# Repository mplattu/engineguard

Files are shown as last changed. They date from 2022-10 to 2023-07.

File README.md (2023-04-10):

# EngineGuard

Yacht engine room monitor based on ESP32 monitoring following sensors:
 * Temperature of engines 1 & 2 (DS18B20 temperature sensor)
 * Temperature of engine room above engines 1 & 2 (DS18B20 temperature sensor)
 * Oil pressure from engines 1 & 2 (+24V DC from VDO oil pressure sensor)
 * Engine room smoke sensor
 * Kitchen gas sensor

Intended operation:
 1. Any of the sensors report an emergency.
 1. An internal buzzers gives signal. This is mainly for debugging the device.
 1. An external 24V device gives signal. The device is connected via a reed relay.
 1. The OLED shows the reason for the alarm.
 1. The external signal can be cut for certain period of time by pressing a button.

## Project Status

 * We have a working code for all the sensors.
 * The PCB v4 was installed to the boat. It turned out that 24V to 5V conversion based on
   the voltage regulator 7805 created too much heat. Therefore, an external step down
   converter was introduced.
 * The PCB v5 has not neither been produced or field tested.

Main unit (green = power, red = activity): \
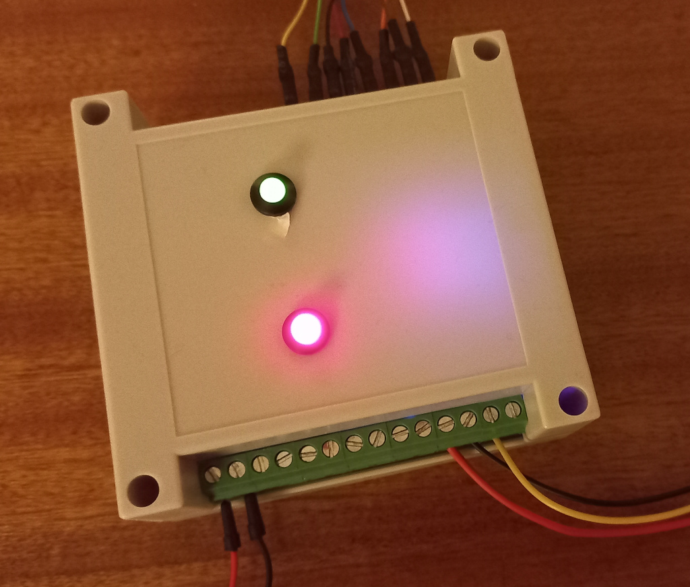
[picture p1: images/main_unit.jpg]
Main unit


Display unit: \
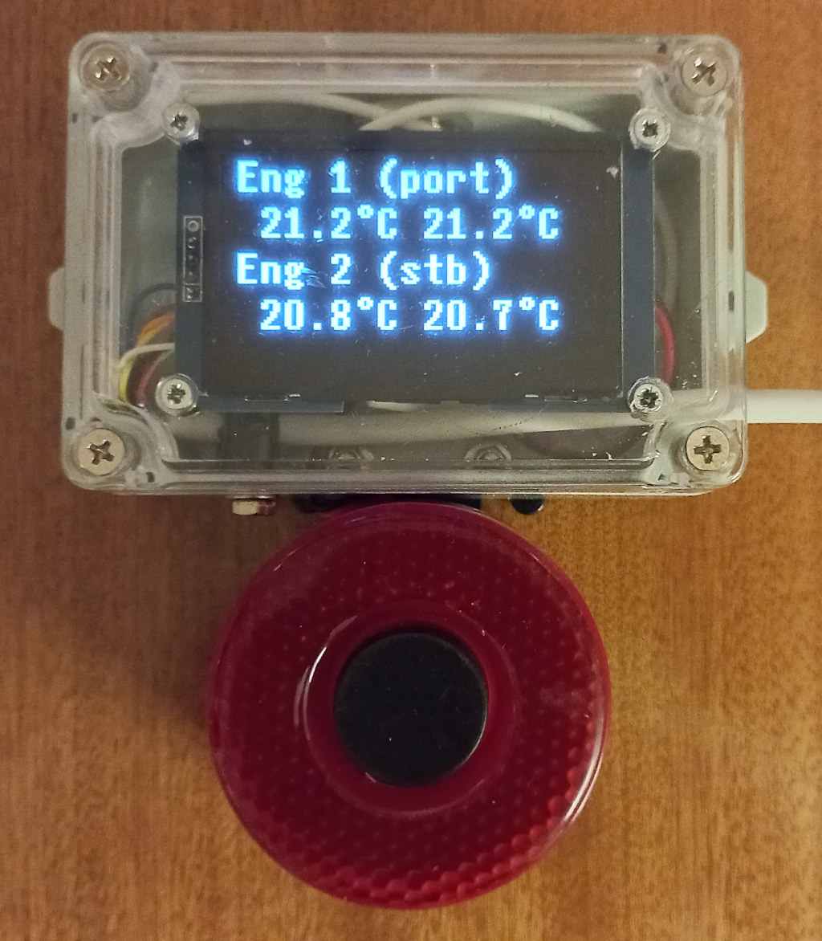
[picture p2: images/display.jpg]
Display


Acknowledgement button mounted to the top of the display unit: \
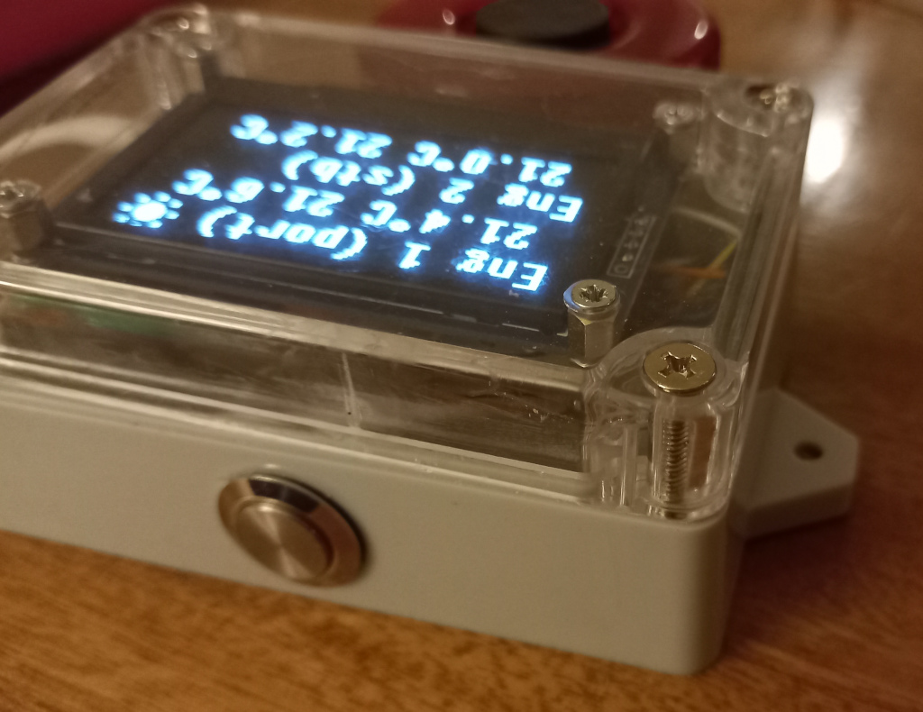
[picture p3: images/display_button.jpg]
Acknowledgement button


PCB: \
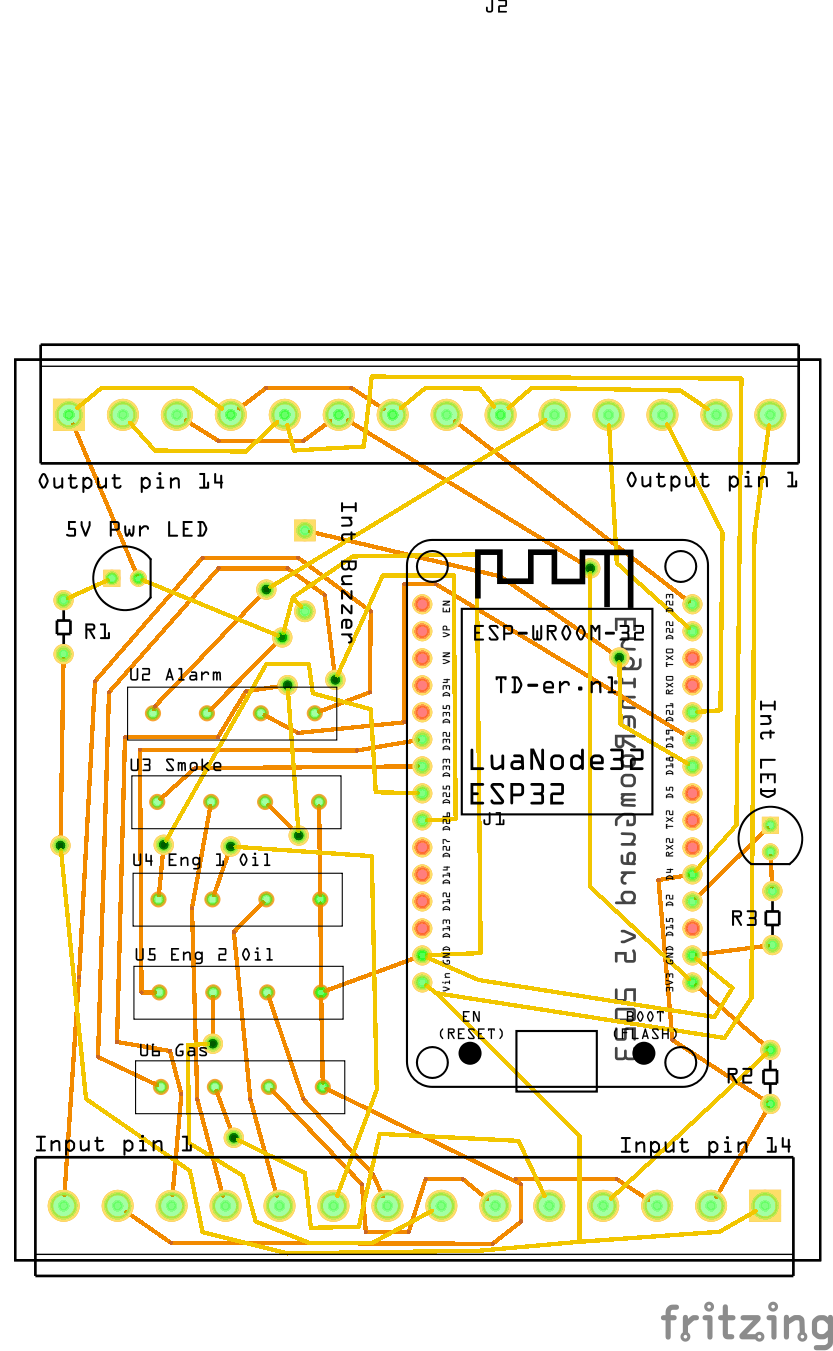
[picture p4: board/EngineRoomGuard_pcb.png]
PCB


## Technical Details

### Schematic and PCBs

See `board/` for Fritzing schematic & PCB and Gerber PCB files.

### Components

* U1 ESP-WROOM-32
* U2 5V reed relay with protective diode, Meder SIL05-1A72-71D ([Local electronics shop](https://www.partco.fi/fi/saehkoemekaniikka/releet/reed-releet/7411-rr-05-sild.html))
* U3-U6 24V reed relay with protective diode, Meder SIL24-1A72-71D ([Local electronics shop](https://www.partco.fi/fi/saehkoemekaniikka/releet/reed-releet/7413-rr-24-sild.html))
* OLED screen with SSD1309 driver, I2C version ([Aliexpress](https://www.aliexpress.com/item/1005003787866468.html))
* LED1, LED2 5mm LED in THT package
* R1 resistor 330 ohm
* R2 resistor 4,7 kOhm
* External DC 24V to DC 5V step down converter ([Joy IT SBC-Buck04-5V](https://joy-it.net/en/products/SBC-Buck04-5V))
* Box for central unit including J1 and J2 ([Aliexpress](https://www.aliexpress.com/item/1005003153480194.html))
* J3 internal piezo 3V ([Local electronics shop](https://www.partco.fi/fi/audiovideo/summerit/20187-summeri-3v.html))
* Box for screen and cancel button ([Aliexpress](https://www.aliexpress.com/item/4000081121421.html))
* Acknowledgement button ([Aliexpress](https://www.aliexpress.com/item/1005003105511055.html))
* Smoke Detector: Orbis Marine Multisensor Detector [ORB-OH-43003-MAR](https://www.apollo-fire.co.uk/products/orbis-marine/smokeheat-detectors/orb-oh-43003-mar---orbis-marine-multi-sensor-detector-opticalheat---flashing-led/) and Orbis Marine Relay Base [ORB-RB-40004-MAR](https://www.apollo-fire.co.uk/products/orbis-marine/relay-bases/orb-rb-40004-mar---orbis-marine-timesaver-base---relay/)
* Gas Sensor: a random 24V gas sensor from Aliexpress (ordered smoke sensor, got gas sensor)

When selecting OLED screen make sure its driver chip is supported by
[u8g2 library](https://github.com/olikraus/u8g2/wiki).

### Connectors

Input

  1. DC VCC (9-32V)
  1. DC GND
  1. Engine room smoke detector (+24V) - GPIO 33
  1. Engine room smoke detector (GND)
  1. Engine 1 Oil (+24V) - GPIO 25
  1. Engine 1 Oil (GND)
  1. Engine 2 Oil (+24V) - GPIO 32
  1. Engine 2 Oil (GND)
  1. Kitchen gas detector (+24V) - GPIO 26
  1. Kitchen gas detector (GND)
  1. Engine room temperature 1-wire, 3V3 (red)
  1. Engine room temperature 1-wire, GND (black)
  1. Engine room temperature 1-wire, signal (yellow) - GPIO 4
  1. DC VCC (5V)

Output

  1. DC +5V (OLED)
  1. DC GND (OLED)
  1. I2C SDA (OLED) - GPIO 21
  1. I2C SCL (OLED) - GPIO 22
  1. Alarm bell (DC VCC 9-32V from input pin 1) - GPIO 19 via relay U2
  1. Alarm bell GND
  1. Clear button A (closed when pressed) - GPIO 23
  1. Clear button A (closed when pressed) - GND
  1. Engine room temperature 1-wire, 3V3 (red)
  1. Engine room temperature 1-wire, signal (yellow) - GPIO 4
  1. Engine room temperature 1-wire, GND (black)
  1. Engine room temperature 1-wire, 3V3 (red)
  1. Engine room temperature 1-wire, signal (yellow) - GPIO 4
  1. Engine room temperature 1-wire, GND (black)
  * Internal buzzer - GPIO 18

## Software

### Building and Uploading the Code

 * Install PlatformIO
 * Copy the configuration template `include/settings.cpp.sample` to `include/settings.cpp`.
   Make necessary changes.
 * If you are planning to use OTA updates copy `include/settings.mk.sample` to `include/settings.mk`.
   Make necessary changes.
 * You'll find more configurations in `src/engineguard.cpp`. If you don't
   have twin engines just remove references to the engine 2. It is OK to comment both
   engines if you don't want to monitor temperatures at all. 
 * `make upload` should build and upload the code to your ESP32 via USB.
 * `make upload_ota` should do the same as OTA update after you have uploaded the first
   version of the code via USB.
 * I had problems uploading the code to an unused ESP32. It appears that my chip was
   missing some boot code. Uploading a simple Hello World from Arduino IDE did the
   trick.

### Configuring Your Engine Guard

Engine Guard is configured by editing `include/settings.cpp` i.e. compile time.

Engine Guard can monitor two temperatures per engine. You can define 0-2 engines.

Configuration procedure (`settings.cpp`):
1. Configure a WiFi network using related variables `WIFI_SSID`, `WIFI_PASS` and `MDNS_NAME`.
1. Set `OTA_PASSWORD` to random string. Don't forget to edit `settings.mk` so you can
   upload new versions using OTA.
1. Set engine name(s) and set some placeholder for temperature sensor 1-wire addresses
   (e.g. "foobar").
1. Upload the first code version via USB and `make upload`. Later you can use `make upload_ota`
   as long as your workstation and Engine Guard are connected to the same network.
1. Connect the first temperature sensor to Engine Guard.
1. Power up the EG and go to (http://eg.local) or any other name you defined by `MDNS_NAME`.
1. The status display should tell you the 1-wire address of the connected sensor.
1. Copy & paste the address to `settings.cpp`.
1. Upload the code and see the status page. Now you should see the sensor being claimed by
   defined task.
1. Repeat the above to define all sensors.

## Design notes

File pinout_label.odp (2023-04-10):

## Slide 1

Lower connector
1 Input DC VCC (9-32V)
2 Input DC GND
3 Engine room smoke det (+24V)
4 Engine room smoke det (GND)
5 Engine 1 Oil (+24V)
6 Engine 1 Oil (GND)
7 Engine 2 Oil (+24V)
8 Engine 2 Oil (GND)
9 Kitchen gas detector (+24V)
10 Kitchen gas detector (GND)
11 Eng room temp, 3V3 (red)
12 Eng room temp, GND (black)
13 Eng room temp, signal (yellow)
14 Input DC VCC (5V)
Upper connector
1 DC +5V (OLED)
2 DC GND (OLED)
3 I2C SDA (OLED)
4 I2C SCL (OLED)
5 Alarm bell (VCC from pin L1)
6 Alarm bell GND
7 Clear button
8 Clear button (GND)
9 Eng room temp, 3V3 (red)
10 Eng room temp, signal (yellow)
11 Eng room temp, GND (black)
12 Eng room temp, 3V3 (red)
13 Eng room temp, signal (yellow)
14 Eng room temp, GND (black)

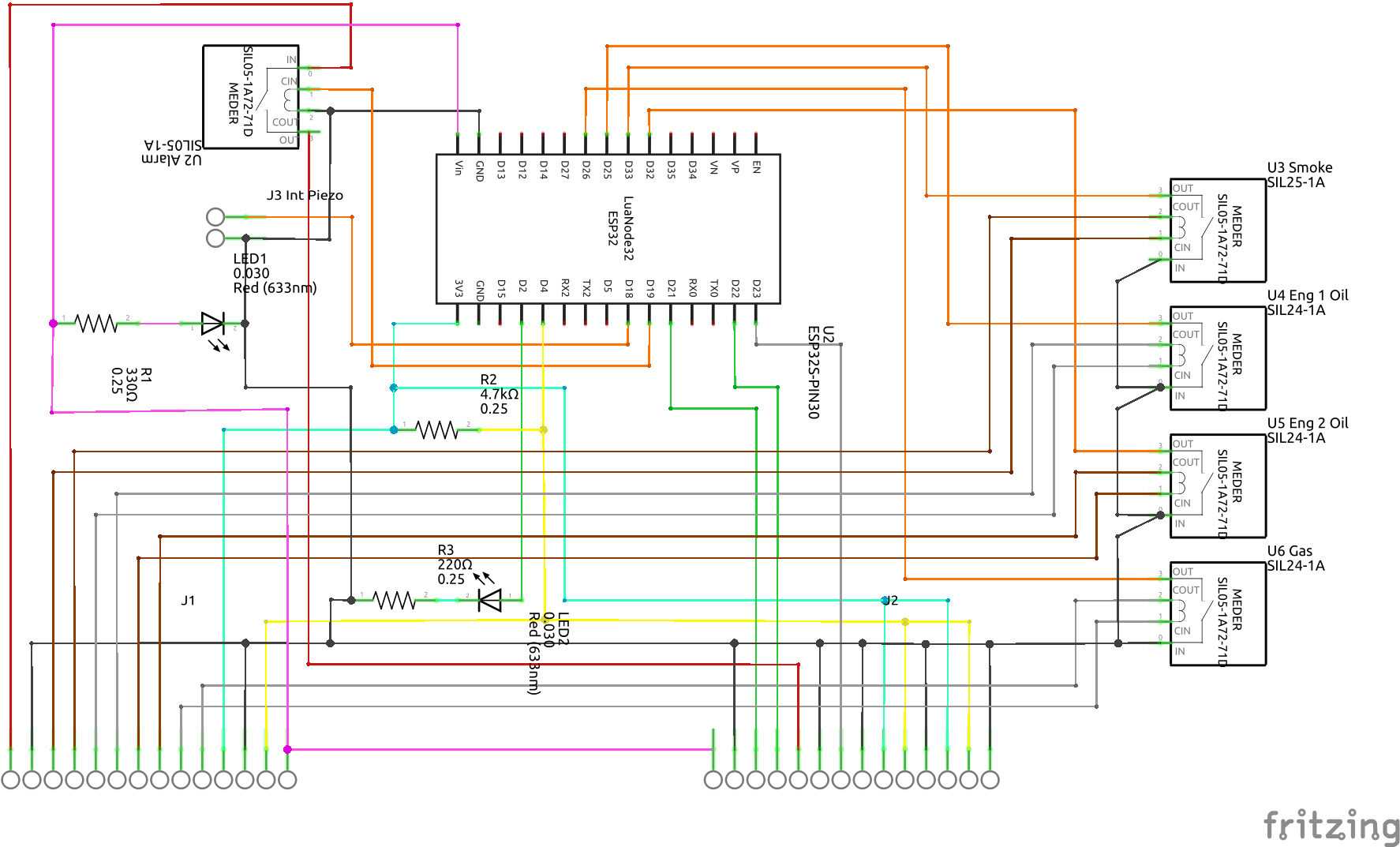
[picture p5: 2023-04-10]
board/EngineRoomGuard_schem.png

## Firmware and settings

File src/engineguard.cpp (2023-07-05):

#include <Arduino.h>
#include <U8g2lib.h>
#include <SPI.h>
#include <Wire.h>
#include <OneWire.h>
#include <DallasTemperature.h>
#include <EspSigK.h>

#include "Engine.h"
#include "DigitalInput.h"
#include "Display.h"
#include "Sound.h"

#define PIN_ONBOARD_LED  2
#define PIN_DISPLAY_CLOCK 22
#define PIN_DISPLAY_DATA 21
#define PIN_ONEWIRE 4
#define PIN_BUZZER_INTERNAL 18
#define PIN_BUZZER_EXTERNAL 19
#define PIN_CLEAR_BUTTON 23
#define CLEAR_BUTTON_VALIDITY_IN_SECONDS 30
#define PIN_INPUT_RELAY_OIL_ENG_1 25
#define PIN_INPUT_RELAY_OIL_ENG_2 32
#define PIN_INPUT_RELAY_SMOKE 33
#define PIN_INPUT_RELAY_GAS 26

#include "../include/settings.cpp"

// Network
#ifdef WIFI_SSID
#define WIFI
#include <WiFi.h>
#include <WebServer.h>
WebServer webServer(80);
WiFiClient wiFiClient;
EspSigK sigK(MDNS_NAME, WIFI_SSID, WIFI_PASS, &wiFiClient);
#endif

#ifdef MDNS_NAME
#ifdef OTA_PASSWORD
#define OTA
#include <ArduinoOTA.h>
#endif
#endif

// Display
U8X8_SSD1309_128X64_NONAME2_SW_I2C u8x8(PIN_DISPLAY_CLOCK, PIN_DISPLAY_DATA);
Display display(&u8x8);

// Onewire and sensors
OneWire oneWire(PIN_ONEWIRE);
DallasTemperature sensors(&oneWire);

Sound sound(PIN_BUZZER_INTERNAL, PIN_BUZZER_EXTERNAL);

// Engines
#ifdef ENGINE1_NAME
#define ENGINE1
Engine engine1(
  ENGINE1_NAME,             // Engine name
  ENGINE1_TEMP_ENG,         // Engine temperature sensor 1-wire address
  ENGINE1_TEMP_ENG_LIMIT,   // Engine temperature emergency limit
  ENGINE1_TEMP_ROOM,        // Room temperature sensor 1-wire address
  ENGINE1_TEMP_ROOM_LIMIT,  // Room temperature emergency limit
  &sensors
);
#endif

#ifdef ENGINE2_NAME
#define ENGINE2
Engine engine2(
  ENGINE2_NAME,             // Engine name
  ENGINE2_TEMP_ENG,         // Engine temperature sensor 1-wire address
  ENGINE2_TEMP_ENG_LIMIT,   // Engine temperature emergency limit
  ENGINE2_TEMP_ROOM,        // Room temperature sensor 1-wire address
  ENGINE2_TEMP_ROOM_LIMIT,  // Room temperature emergency limit
  &sensors
);
#endif

#ifdef ENGINE1
DigitalInput alarmOilEngine1("Engine 1", PIN_INPUT_RELAY_OIL_ENG_1, "Oil Pressure");
#endif
#ifdef ENGINE2
DigitalInput alarmOilEngine2("Engine 2", PIN_INPUT_RELAY_OIL_ENG_2, "Oil Pressure");
#endif
DigitalInput alarmSmoke("Engine Room", PIN_INPUT_RELAY_SMOKE, "Smoke Alarm");
DigitalInput alarmGas("Kitchen", PIN_INPUT_RELAY_GAS, "Gas Alarm");

// Unfortunately the interrupt-related stuff (namely the button) has to be a static
// function. So no class-stuff here!
#include "../lib/button.cpp"

#ifdef OTA
#include "../lib/ota.cpp"
#endif

#ifdef WIFI
void showDeviceStatus() {
  String text = "EngineGuard: " + String(MDNS_NAME) + "\n\n";

#ifdef ENGINE1
  text = text + "Status for engine 1:\n\n" + engine1.getStatus() + "\n\n";
#else
  text = text + "Engine 1 is not defined\n\n";
#endif

#ifdef ENGINE2
  text = text + "Status for engine 2:\n\n" + engine2.getStatus() + "\n\n";
#else
  text = text + "Engine 2 is not defined\n\n";
#endif

  webServer.send(200, "text/plain", text);
}
#endif

bool wifiConnected() {
#ifdef WIFI
  return (WiFi.status() == WL_CONNECTED);
#else
  return false;
#endif  
}

void setup(void) {
  pinMode(PIN_ONBOARD_LED, OUTPUT);
  digitalWrite(PIN_ONBOARD_LED, HIGH);

  Serial.begin(115200);

  display.showMessage("Init: Sensors");

  sensors.begin();

  display.showMessage("Init: Button");
  buttonSetup(PIN_CLEAR_BUTTON, CLEAR_BUTTON_VALIDITY_IN_SECONDS);

#ifdef WIFI
  sigK.setServerHost(SIGNALK_SERVER_IP);
  sigK.setServerPort(SIGNALK_SERVER_PORT);
  sigK.setPrintDebugSerial(true);

  display.showMessage("Init: SignalK");
  sigK.begin();

  display.showMessage("Init: Webserver"); 
  webServer.on("/", showDeviceStatus);
  webServer.begin();
#endif

#ifdef OTA
  display.showMessage("Init: OTA");
  Serial.print("Initialising OTA...");
  initialiseArduinoOTA((char*)MDNS_NAME, (char*)OTA_PASSWORD);
  Serial.println("OK");
#endif

#ifdef ENGINE1
  #ifdef ENGINE2
  display.showEmergencyLimits(&engine1, &engine2);
  #else
  display.showEmergencyLimits(&engine1);
  #endif
  delay(3000);
#endif

  display.clearDisplay();
}

EmergencyReason getZeroEmergencyReason(void) {
  EmergencyReason zeroEmergencyReason;

  zeroEmergencyReason.isEmergency = false;
  zeroEmergencyReason.target = "";
  zeroEmergencyReason.reason = "";
  zeroEmergencyReason.hasValue = false;
  zeroEmergencyReason.value = "";

  return zeroEmergencyReason;
}

EmergencyReason checkEmergency(void) {
#ifdef ENGINE1
  if (engine1.isEmergency()) {
    return engine1.getEmergencyReason();
  }

  if (alarmOilEngine1.isEmergency()) {
    return alarmOilEngine1.getEmergencyReason();
  }
#endif

#ifdef ENGINE2
  if (engine2.isEmergency()) {
    return engine2.getEmergencyReason();
  }

  if (alarmOilEngine2.isEmergency()) {
    return alarmOilEngine2.getEmergencyReason();
  }
#endif

  if (alarmSmoke.isEmergency()) {
    return alarmSmoke.getEmergencyReason();
  }

  if (alarmGas.isEmergency()) {
    return alarmGas.getEmergencyReason();
  }

  return getZeroEmergencyReason();
}

void safeDelay(unsigned long ms) {
#ifdef WIFI
  sigK.safeDelay(ms);
#else
  delay(ms);
#endif
}

int getCelsiusInKelvin(float tempCelsius) {
  return (int)(tempCelsius + 273.15);
}

void loop(void) {
  Serial.println("---");

#ifdef ENGINE1
  engine1.readSensors();
#endif

#ifdef ENGINE2
  engine2.readSensors();
#endif

  const EmergencyReason EmergencyReason = checkEmergency();

#ifndef ENGINE1
  display.updateDisplay(EmergencyReason, wifiConnected());
#else
  #ifndef ENGINE2
  display.updateDisplay(&engine1, EmergencyReason, wifiConnected());
  #else
  display.updateDisplay(&engine1, &engine2, EmergencyReason, wifiConnected());
  #endif
#endif

  sound.updateSignal(EmergencyReason, buttonPressIsStillValid());

  buttonLoop();

  digitalWrite(PIN_ONBOARD_LED, LOW);
  safeDelay(250);
  digitalWrite(PIN_ONBOARD_LED, HIGH);
  safeDelay(250);

#ifdef WIFI
#ifdef ENGINE1
  sigK.addDeltaValue("propulsion.port.coolantTemperature", getCelsiusInKelvin(engine1.getTemperatureEngine()));
  sigK.addDeltaValue("environment.inside.engineroomPort.temperature", getCelsiusInKelvin(engine1.getTemperatureRoom()));
#endif
#ifdef ENGINE2
  sigK.addDeltaValue("propulsion.starboard.coolantTemperature", getCelsiusInKelvin(engine2.getTemperatureEngine()));
  sigK.addDeltaValue("environment.inside.engineroomStarboard.temperature", getCelsiusInKelvin(engine2.getTemperatureRoom()));
#endif
  sigK.sendDelta();
  webServer.handleClient();
#endif

#ifdef OTA
  ArduinoOTA.handle();
#endif
}

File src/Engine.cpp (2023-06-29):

#include "Engine.h"

Engine::Engine(String engineName, String onewireAddressEngine, float emergencyLimitEngine, String onewireAddressRoom, float emergencyLimitRoom, DallasTemperature * sensors) {
  this->engineName = engineName;
  this->onewireAddressEngine = onewireAddressEngine;
  this->onewireAddressRoom = onewireAddressRoom;
  this->emergencyLimitEngine = emergencyLimitEngine;
  this->emergencyLimitRoom = emergencyLimitRoom;

  this->lastTemperatureEngine = 0.0;
  this->lastTemperatureRoom = 0.0;

  this->onewireSensors = sensors;

  this->lastReadStatus = "";
}

String Engine::getName() {
  return this->engineName;
}

String Engine::getEmergencyLimitEngineStr() {
  float temperature = this->emergencyLimitEngine;

  return String(temperature, 1) + "°C";
}

String Engine::getEmergencyLimitRoomStr() {
  float temperature = this->emergencyLimitRoom;

  return String(temperature, 1) + "°C";
}

String Engine::getStatus() {
  String statusText = "";
  statusText += "Engine name: " + this->getName() + "\n";
  statusText += "Engine sensor address: " + this->onewireAddressEngine + "\n";
  statusText += "Room sensor address: " + this->onewireAddressRoom + "\n";

  statusText += this->lastReadStatus;

  return statusText;
}

void Engine::readSensors() {
  String newStatus = "";
  int numberOfSensors = this->onewireSensors->getDeviceCount();

  this->onewireSensors->requestTemperatures();

  DeviceAddress currentDeviceAddress;
  String currentDeviceAddressStr;

  if (numberOfSensors == 0) {
    newStatus += "No devices found\n";
  }

  for (int i=0; i < numberOfSensors; i++) {
    if (this->onewireSensors->getAddress(currentDeviceAddress, i)) {
      currentDeviceAddressStr = this->oneWireDeviceAddressToString(currentDeviceAddress);

      Serial.print(currentDeviceAddressStr + " ");
      newStatus += String(i) + ": " + currentDeviceAddressStr;

      float temperature = this->onewireSensors->getTempC(currentDeviceAddress);
      Serial.print(temperature);
      newStatus += " temp: " + String(temperature);

      if (currentDeviceAddressStr == this->onewireAddressEngine) {
        Serial.print(" belongs to " + this->engineName + " (engine)");
        newStatus += " (engine)";
        this->lastTemperatureEngine = temperature;
      }

      if (currentDeviceAddressStr == this->onewireAddressRoom) {
        Serial.print(" belongs to " + this->engineName + " (room)");
        newStatus += " (room)";
        this->lastTemperatureRoom = temperature;
      }

      Serial.println();
      newStatus += "\n";
    }
  }

  this->lastReadStatus = newStatus;
}

float Engine::getTemperatureEngine() {
  return this->lastTemperatureEngine;
}

String Engine::getTemperatureEngineStr() {
  float temperature = this->getTemperatureEngine();

  return String(temperature, 1) + "°C";
}

float Engine::getTemperatureRoom() {
  return this->lastTemperatureRoom;
}

String Engine::getTemperatureRoomStr() {
  float temperature = this->getTemperatureRoom();

  return String(temperature, 1) + "°C";
}

bool Engine::isEmergency() {
  if (this->lastTemperatureEngine > this->emergencyLimitEngine) {
    this->lastEmergencyReason.isEmergency = true;
    this->lastEmergencyReason.target = this->engineName;
    this->lastEmergencyReason.reason = "Engine temp";
    this->lastEmergencyReason.value = this->getTemperatureEngineStr();
    this->lastEmergencyReason.hasValue = true;

    return true;
  }

  if (this->lastTemperatureRoom > this->emergencyLimitRoom) {
    this->lastEmergencyReason.isEmergency = true;
    this->lastEmergencyReason.target = this->engineName;
    this->lastEmergencyReason.reason = "Eng room temp";
    this->lastEmergencyReason.value = this->getTemperatureRoomStr();
    this->lastEmergencyReason.hasValue = true;

    return true;
  }

  this->lastEmergencyReason = getZeroEmergencyReason();
  
  return false;
}

EmergencyReason Engine::getEmergencyReason() {
  return this->lastEmergencyReason;
}

String Engine::oneWireDeviceAddressToString(DeviceAddress onewireAddress) {
  String onewireAddressStr = "";

  for (uint8_t i = 0; i < 8; i++){
    if (onewireAddress[i] < 16) {
      onewireAddressStr += "0";
    }
    onewireAddressStr += String(onewireAddress[i], HEX);
  }

  return onewireAddressStr;
}

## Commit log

2022-08-15 Read and show temperatures on OLED display
2022-08-16 Added temperature emergency limits and warning
2022-08-16 Added instructions for identifying sensors
2022-08-16 Added internal alert buzzer
    [Sound.cpp, engineguard.cpp]
2022-08-16 Added support for external buzzer relay
    [Sound.cpp, engineguard.cpp]
2022-08-19 Added button to temporary suppress external alarm signal
2022-08-19 Blink led
2022-08-19 Drive internal buzzer in ESP32 to get rid of the error messages
    [Sound.cpp]
2022-08-20 Added digital inputs (smoke, oil pressure)
2022-08-20 Added board v1
    [EngineRoomGuard.fzz]
2022-08-21 Fixed several wirings, PCB v2 to production
    [EngineRoomGuard.fzz]
2022-09-14 Fixed more wirings after receiving PCB v2, v3 to production
    [EngineRoomGuard.fzz]
2022-10-23 Reboot after failed WiFi connection to make OTA updates more robust
    [engineguard.cpp]
2022-10-30 Signal OTA update with internal LED and display
2022-10-30 Added prototype images and gas sensor documentation
2022-11-20 Fixed PCB v3 bugs, added Gerber files, updated project status
    [EngineRoomGuard.fzz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]
2022-12-18 Added label for central unit case
2023-04-10 Removed 7805 and fixed connector labels * The voltage regulator 7805 created too much heat so it was replaced with an external power supply. * Fixed labels in thermostatic 1-wire connectors.
    [EngineRoomGuard.fzz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]
2023-05-12 Send temperatures to SignalK server, improved startup debug messages
2023-07-05 Fixed temperature conversion
